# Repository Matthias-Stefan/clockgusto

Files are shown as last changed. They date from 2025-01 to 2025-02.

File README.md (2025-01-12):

# CLOCKGUSTO

This project is about adapting the original QLOCKTWO to a new format. The QLOCKTWO is a unique clock that displays time in words rather than numbers, with illuminated letters forming phrases such as "IT IS HALF PAST TEN."

## Features

- **Minute Precision:** Each illuminated dot represents one minute past the hour.
- **Word-Based Time Display:** The clock displays time using words for a more intuitive reading experience.
- **REST API:** Allows for remote adjustment of the time settings via a RESTful API.
- **Android App Integration:** An Android app is available to adjust the time and retrieve log information.

## Time Display Examples
In the default setting, the introductory words "ES IST" (IT IS) are shown at full and half hours. Here are some examples of how the time is displayed:

- 00:00: ES IST ZWÖLF UHR (It is twelve o'clock)
- 00:05: FÜNF NACH ZWÖLF (Five past twelve)
- 00:10: ZEHN NACH ZWÖLF (Ten past twelve)
- 00:15: VIERTEL EINS (Quarter past twelve)
- 00:20: ZWANZIG NACH ZWÖLF (Twenty past twelve)
- 00:25: FÜNF VOR HALB EINS (Five to half past twelve)
- 00:30: ES IST HALB EINS (It is half past twelve)
- 00:35: FÜNF NACH HALB EINS (Five past half past twelve)
- 00:40: ZWANZIG VOR EINS (Twenty to one)
- 00:45: DREIVIERTEL EINS (Three-quarters to one)
- 00:50: ZEHN VOR EINS (Ten to one)
- 00:55: FÜNF VOR EINS (Five to one)
- 01:00: ES IST EIN UHR (It is one o'clock)

## Character Map Layout
```
.                       .
  
  E S K I S T A F Ü N F 		   
  Z E H N Z W A N Z I G 
  D R E I V I E R T E L 
  V O R F U N K N A C H 
  H A L B A E L F Ü N F
  E I N S X A M Z W E I
  D R E I P M J V I E R
  S E C H S N L A C H T
  S I E B E N Z W Ö L F
  Z E H N E U N K U H R

.                       .
```
## ESP LED Indices Plan
```
113 112
  .   .

 0  1  2  3  4  5  6  7  8  9 10
 E  S  K  I  S  T  A  F  Ü  N  F 	

21 20 19 18 17 16 15 14 13 12 11	   
 Z  E  H  N  Z  W  A  N  Z  I  G 
  
22 23 24 25 26 27 28 29 30 31 32
 D  R  E  I  V  I  E  R  T  E  L

43 42 41 40 39 38 37 36 35 34 33 
 V  O  R  F  U  N  K  N  A  C  H 

44 45 46 47 48 49 50 51 52 53 54
 H  A  L  B  A  E  L  F  Ü  N  F

65 64 63 62 61 60 59 58 57 56 55
 E  I  N  S  X  A  M  Z  W  E  I

66 67 68 69 70 71 72 73 74 75 76
 D  R  E  I  P  M  J  V  I  E  R

87 86 85 84 83 82 81 80 79 78 77
 S  E  C  H  S  N  L  A  C  H  T

88 89 90 91 92 93 94 95 96 97 98
 S  I  E  B  E  N  Z  W  Ö  L  F

109 108 107 106 105 104 103 102 101 100 99
 Z   E   H   N   E   U   N   K   U   H   R

 110 111
  .   .
```

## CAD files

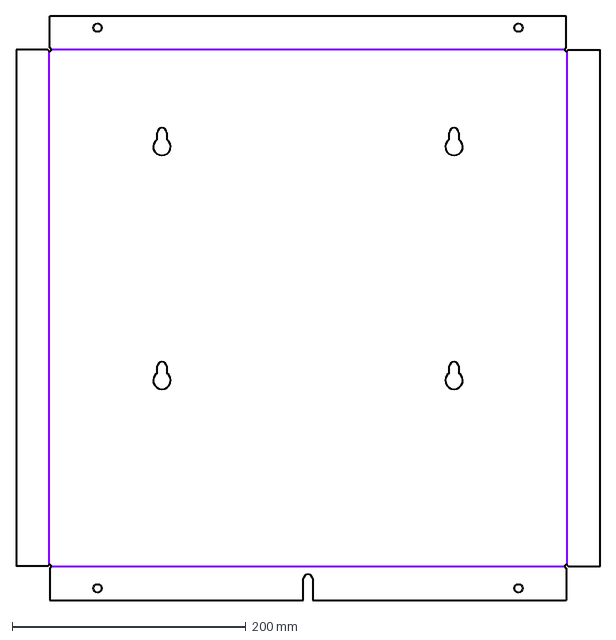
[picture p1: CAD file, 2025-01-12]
construction/02 Korpus.dxf
499.5 x 499.5 mm

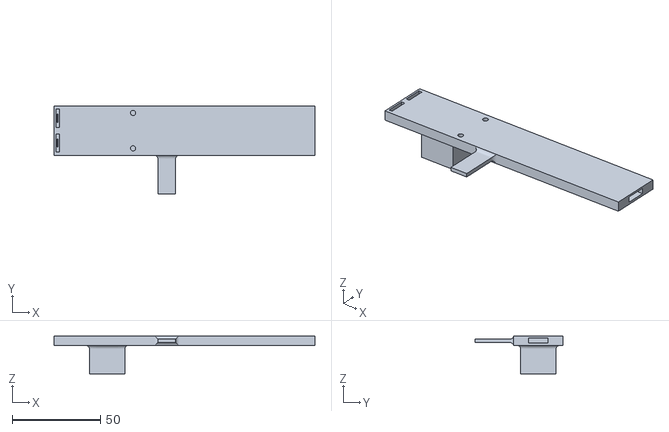
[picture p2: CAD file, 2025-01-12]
construction/printing/connector_a.stl
147.5 x 49.9 x 21.3

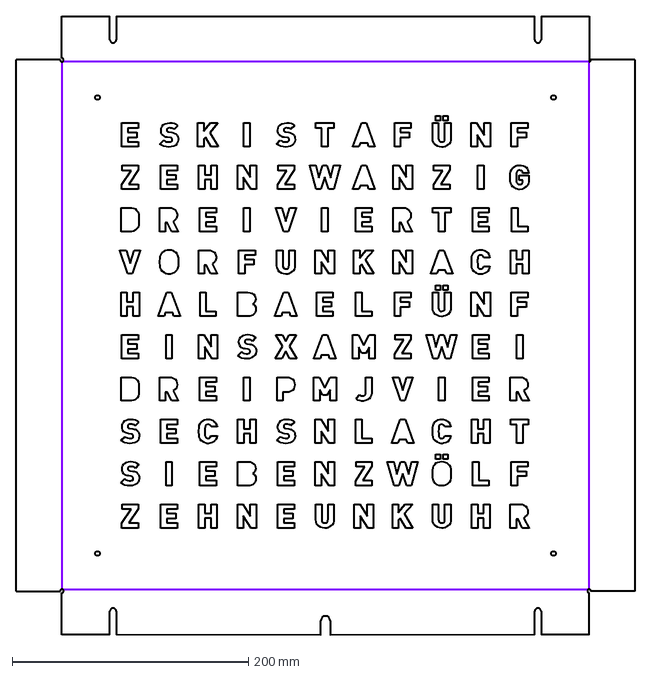
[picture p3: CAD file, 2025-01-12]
construction/01 Ziffernblatt.dxf
524.5 x 524.5 mm

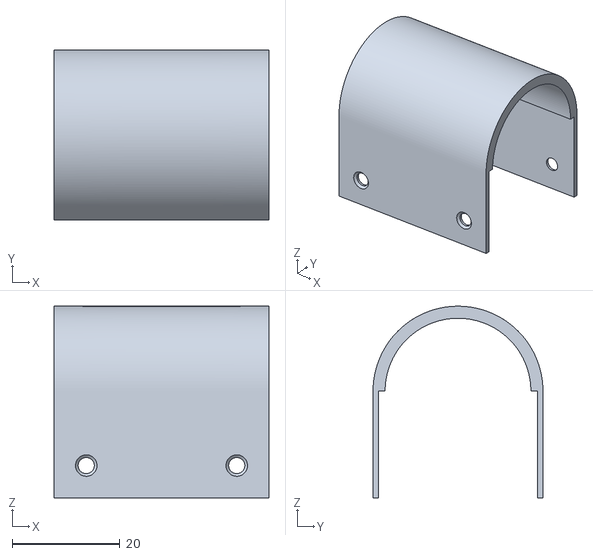
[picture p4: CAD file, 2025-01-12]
construction/printing/powerbank_case_top.stl
40.0 x 31.6 x 35.6

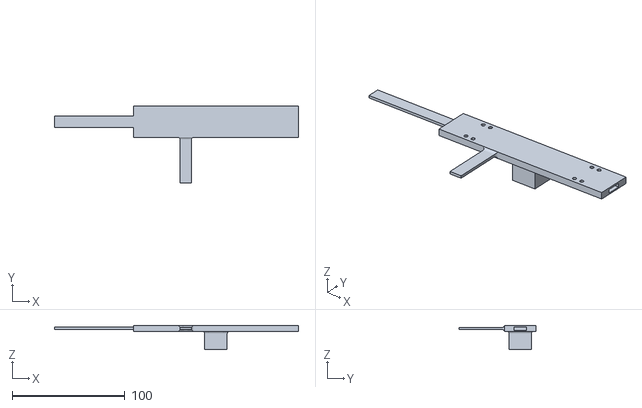
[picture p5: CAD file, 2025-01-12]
construction/connector_base_b.stl
216.5 x 68.4 x 21.3

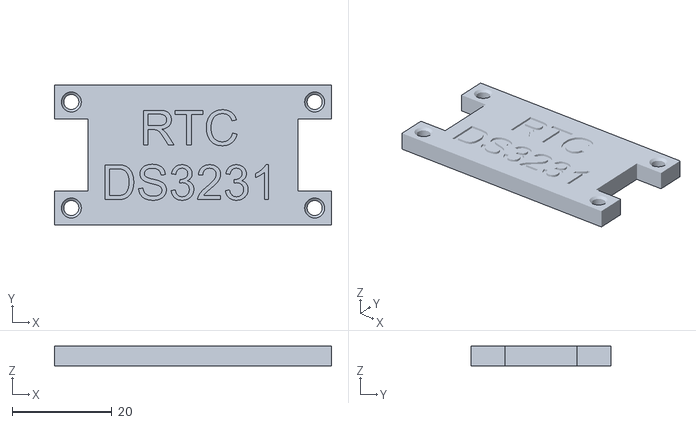
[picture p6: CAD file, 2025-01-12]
construction/printing/ds3231_case_top.stl
55.5 x 28.0 x 4.00

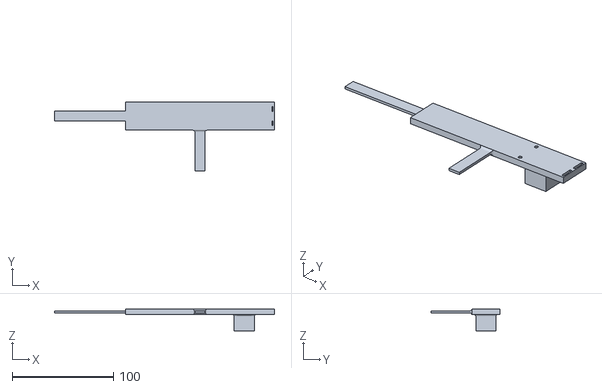
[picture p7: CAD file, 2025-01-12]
construction/connector_base_c.stl
217.5 x 68.4 x 21.3

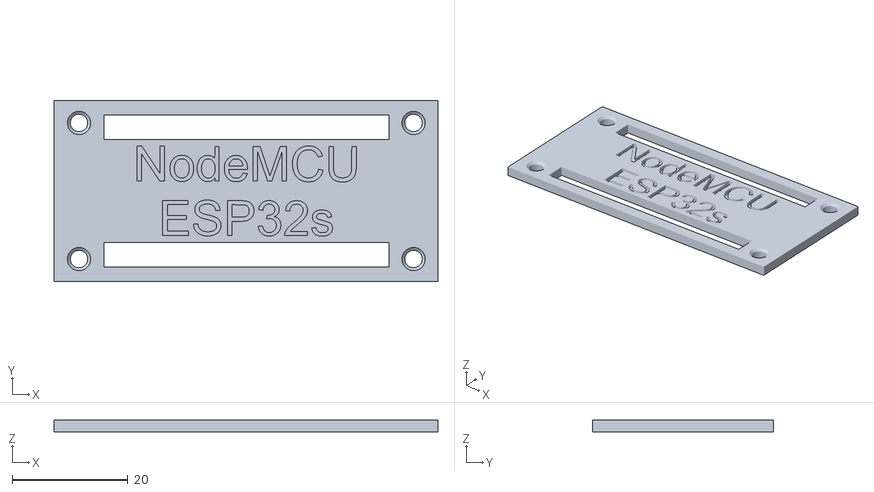
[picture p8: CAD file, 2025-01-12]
construction/printing/nodemcu esp32s_case_top.stl
66.2 x 31.2 x 2.00

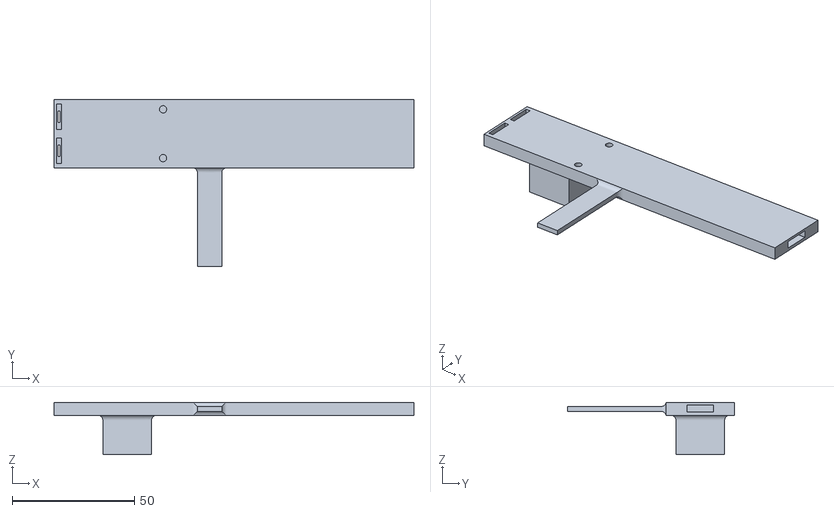
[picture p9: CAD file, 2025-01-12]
construction/connector_base_a.stl
147.5 x 68.4 x 21.3

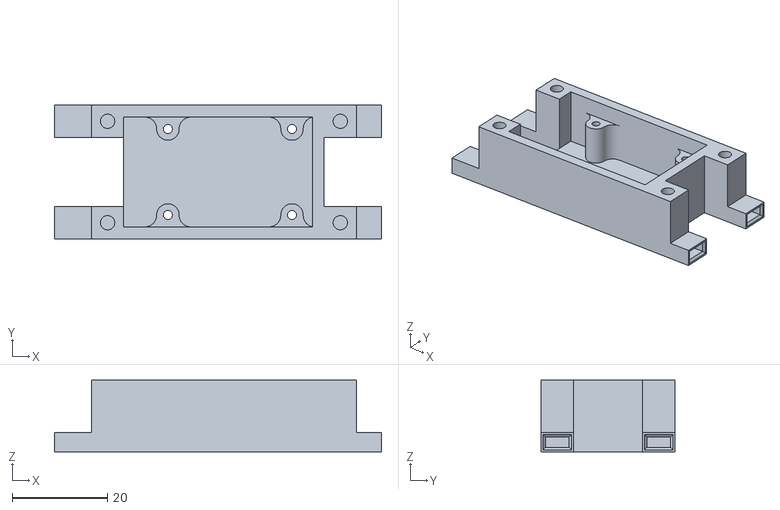
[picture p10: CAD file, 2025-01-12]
construction/printing/ds3231_case_bottom.stl
68.5 x 28.0 x 15.0

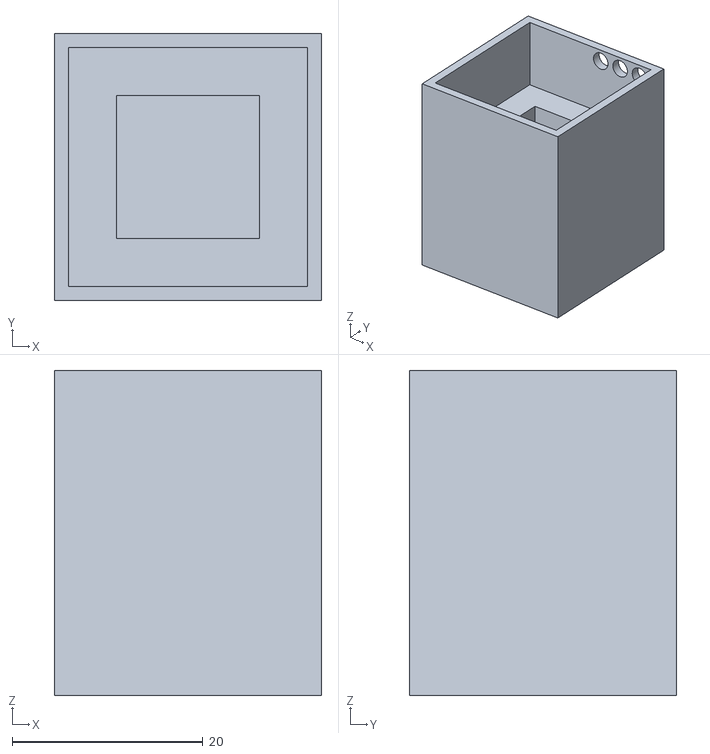
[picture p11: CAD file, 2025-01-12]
construction/printing/minute_tower.stl
28.0 x 28.0 x 34.0

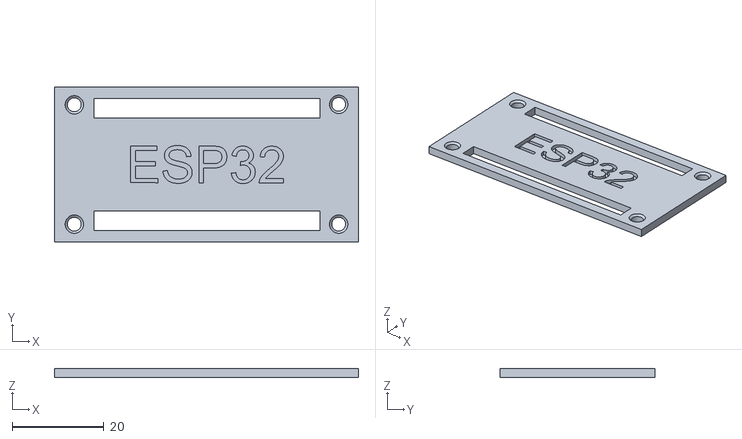
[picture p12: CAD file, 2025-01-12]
construction/printing/esp32 devkitc_v4_case_top.stl
66.2 x 33.8 x 2.00

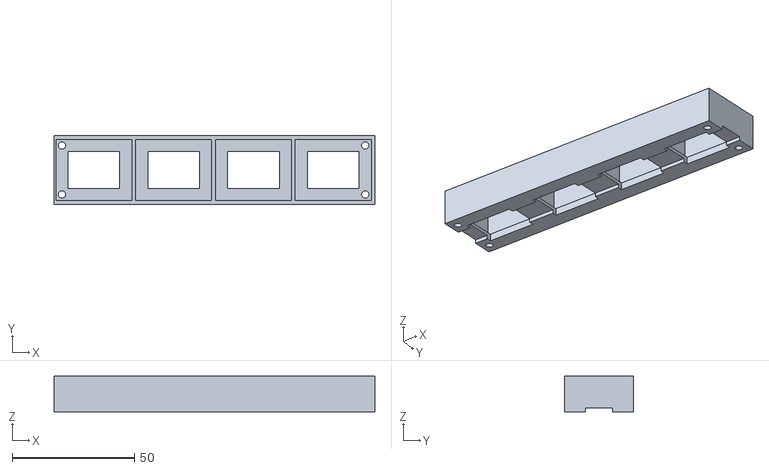
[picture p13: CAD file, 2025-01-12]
construction/printing/separator_4x_2.stl
131.2 x 28.0 x 14.7

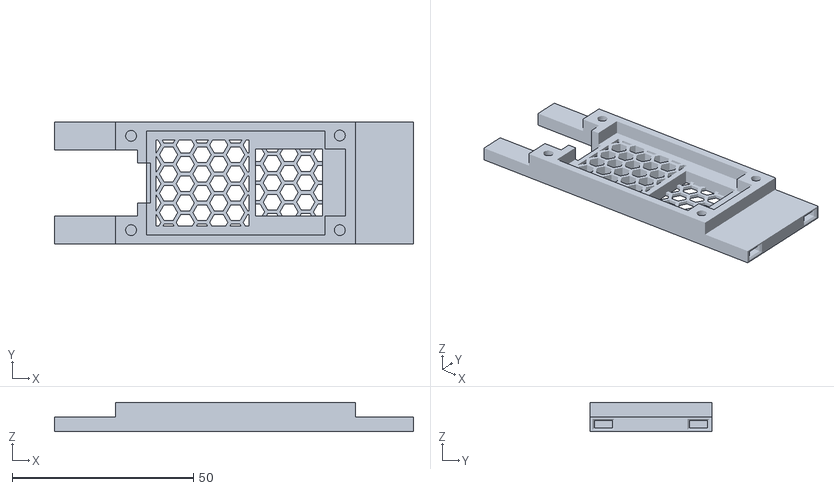
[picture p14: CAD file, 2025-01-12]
construction/printing/esp32 devkitc_v4_case_bottom.stl
99.0 x 33.8 x 8.00

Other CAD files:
construction/printing/connector_b.stl
construction/printing/antenna_nupsi.stl
construction/printing/separator_4x_1.stl
construction/printing/nodemcu esp32s_case_bottom.stl
construction/01 Ziffernblatt v4.f3d
construction/01 Ziffernblatt.dwg
construction/02 Korpus v42.f3d
construction/02 Korpus.dwg
construction/04 DS3231 v7.f3d
construction/05 Powerbank v7.f3d
construction/06 Antenna v4.f3d
construction/printing/connector_base_a.stl
construction/printing/connector_base_b.stl
construction/printing/connector_base_c.stl
construction/printing/connector_c.stl
construction/printing/connector_separator.3mf
construction/printing/powerbank_case_bottom.stl
construction/printing/separator_3x_1.stl

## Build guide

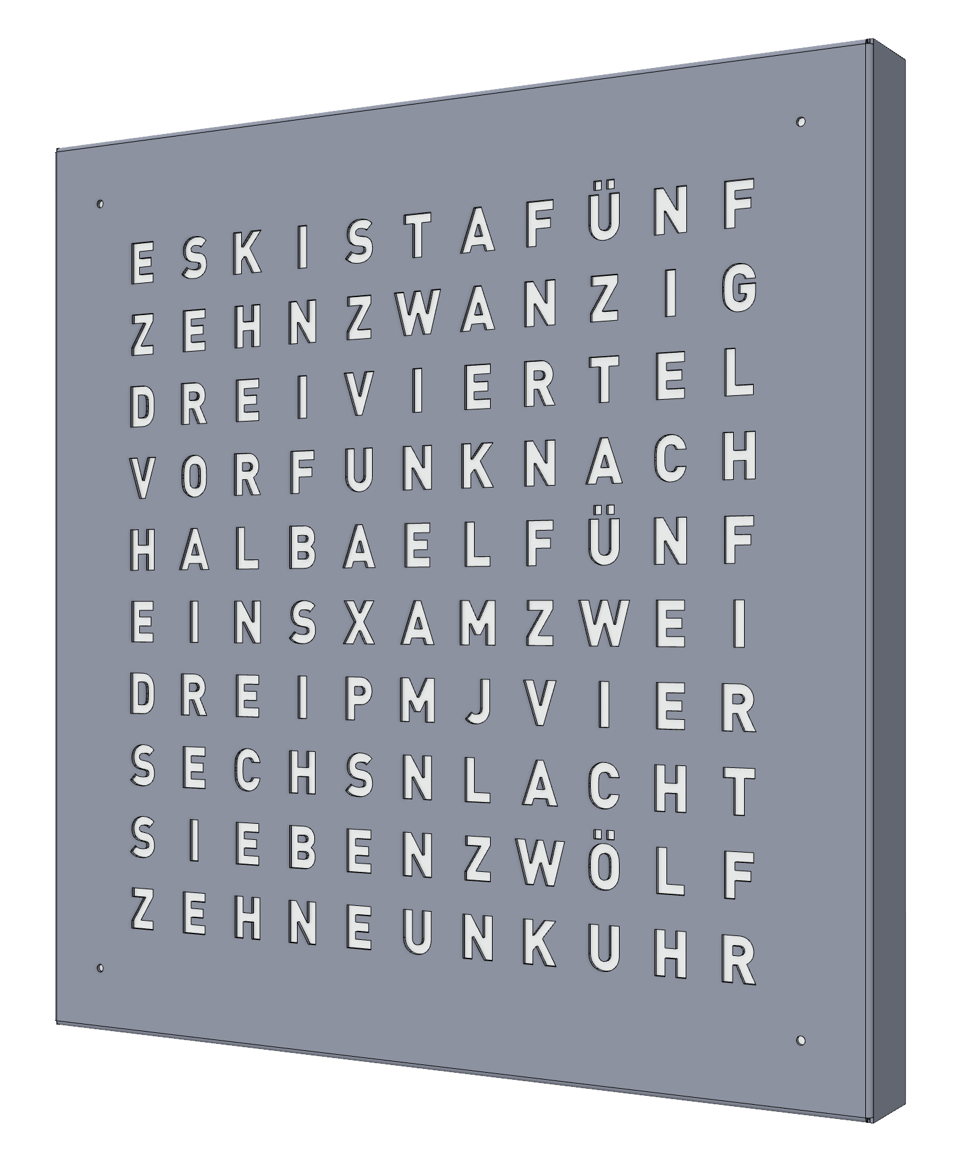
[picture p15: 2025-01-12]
construction/00 Uhr Michelle.png

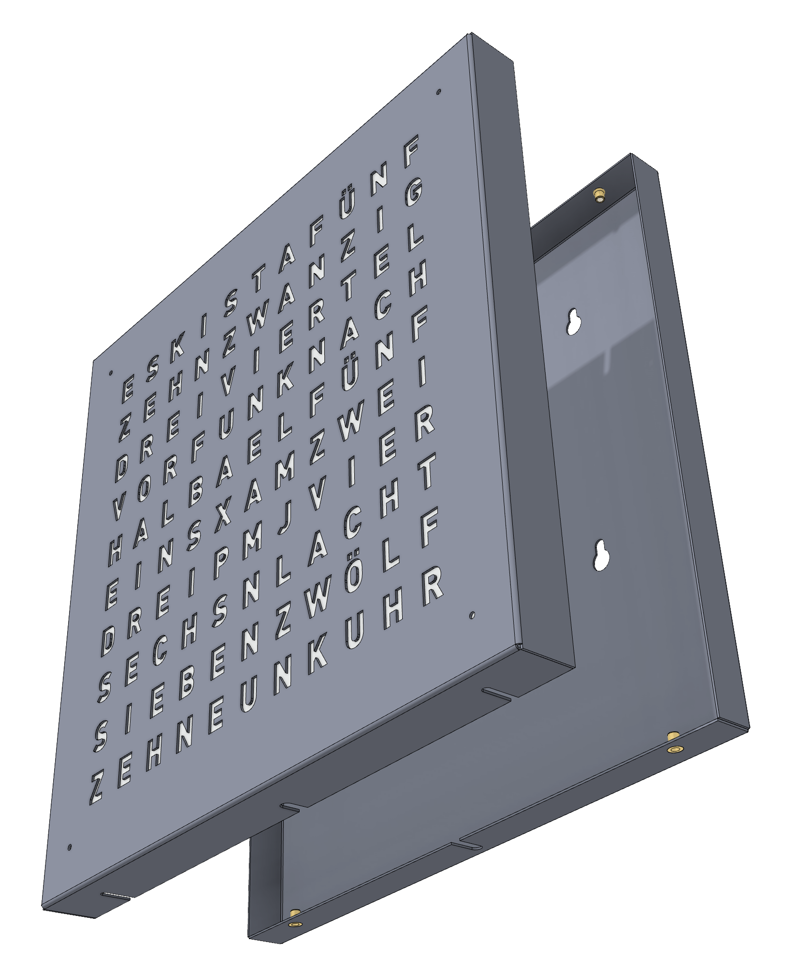
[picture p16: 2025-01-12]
construction/01 Uhr Michelle.png

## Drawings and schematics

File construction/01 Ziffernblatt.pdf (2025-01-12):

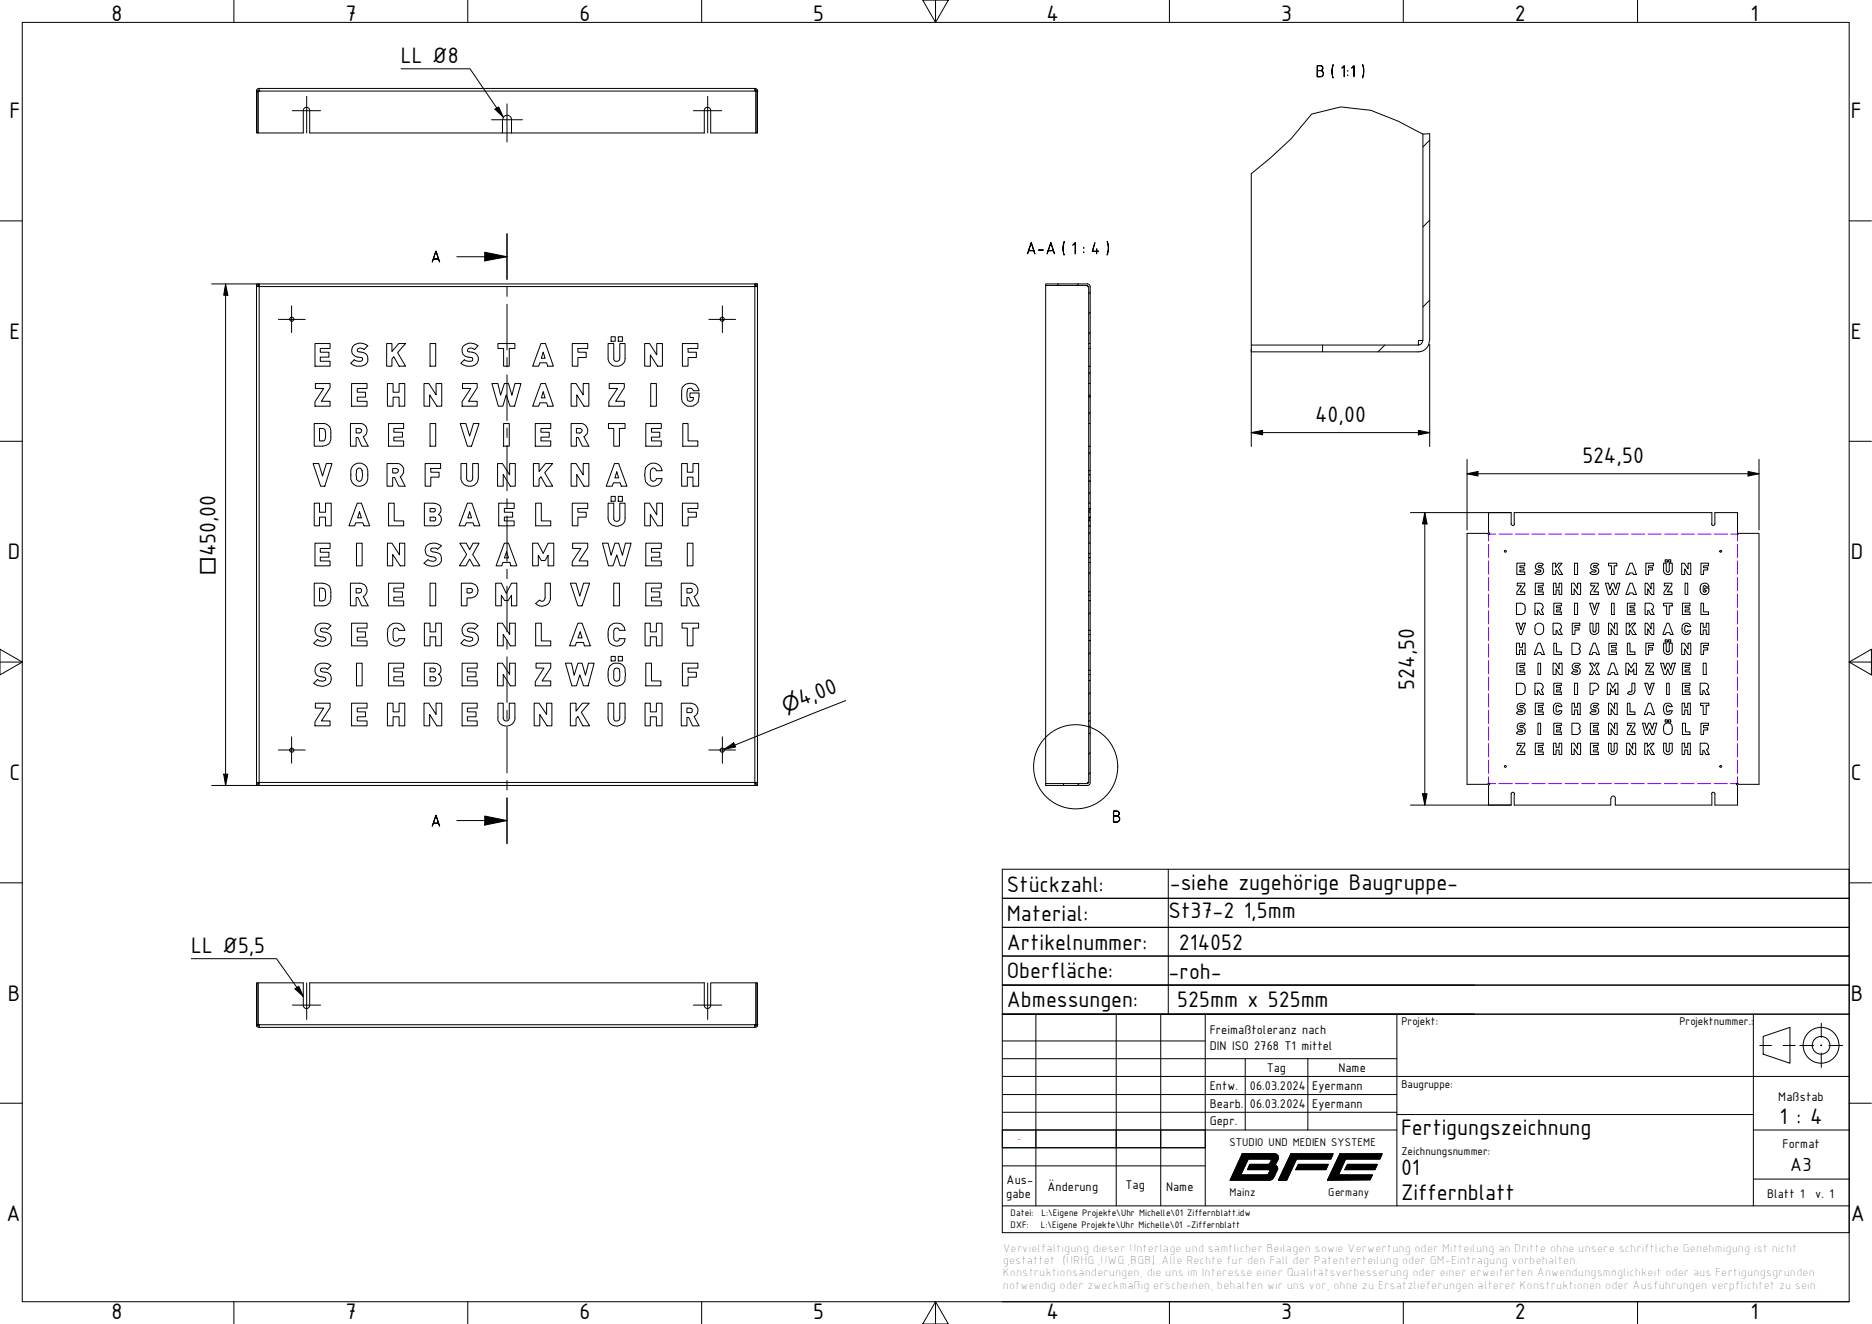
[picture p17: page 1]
Blatt 1 v. 1; DXF:; L:\Eigene Projekte\Uhr Michelle\01 -Ziffernblatt

Stückzahl: | -siehe zugehörige Baugruppe-
Material: | St37-2 1,5mm
Artikelnummer: | 214052
Oberfläche: | -roh-
Abmessungen: | 525mm x 525mm

Freimaßtoleranz nach DIN ISO 2768 T1 mittel | Projekt: Projektnummer.:

Tag | Name

Entw. | 06.03.2024 | Eyermann | Baugruppe: | Maßstab 1 : 4
Bearb. | 06.03.2024 | Eyermann
Gepr. | | | Fertigungszeichnung Fertigungszeichnung Zeichnungsnummer: 01 01 Ziffernblatt Ziffernblatt

STUDIO UND MEDIEN SYSTEME

Datei: L:\Eigene Projekte\Uhr Michelle\01 Ziffernblatt.idw
Vervielfältigung dieser Unterlage und sämtlicher Beilagen sowie Verwertung oder Mitteilung an Dritte ohne unsere schriftliche Genehmigung ist nicht
gestattet (URHG.,UWG.,BGB). Alle Rechte für den Fall der Patenterteilung oder GM-Eintragung vorbehalten.
Konstruktionsänderungen, die uns im Interesse einer Qualitätsverbesserung oder einer erweiterten Anwendungsmöglichkeit oder aus Fertigungsgründen
notwendig oder zweckmäßig erscheinen, behalten wir uns vor, ohne zu Ersatzlieferungen älterer Konstruktionen oder Ausführungen verpflichtet zu sein.

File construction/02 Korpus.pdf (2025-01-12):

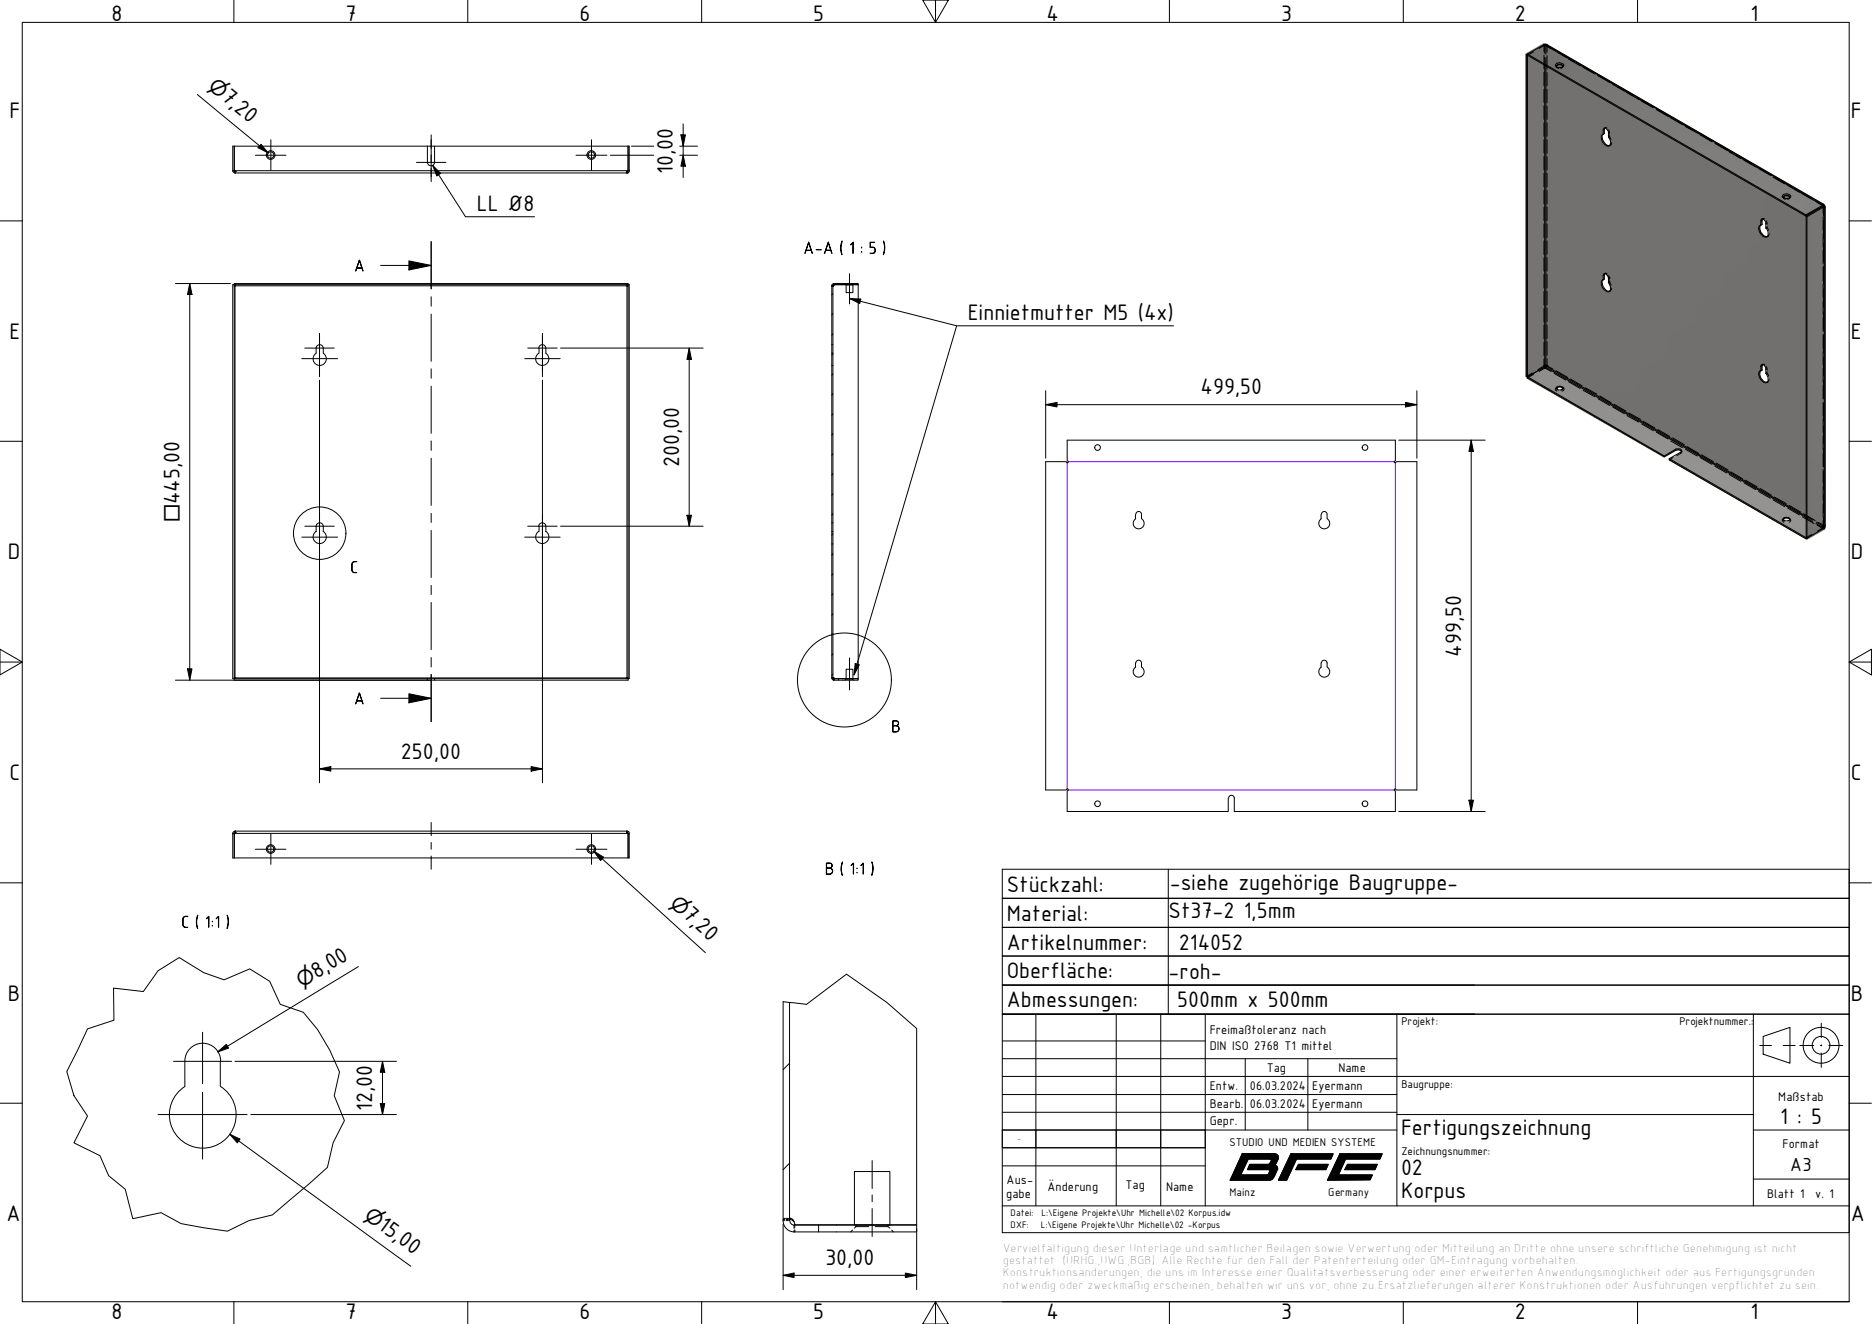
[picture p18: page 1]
Blatt 1 v. 1; DXF:; L:\Eigene Projekte\Uhr Michelle\02 -Korpus; Einnietmutter M5 (4x)

Stückzahl: | -siehe zugehörige Baugruppe-
Material: | St37-2 1,5mm
Artikelnummer: | 214052
Oberfläche: | -roh-
Abmessungen: | 500mm x 500mm

Freimaßtoleranz nach DIN ISO 2768 T1 mittel | Projekt: Projektnummer.:

Tag | Name

Entw. | 06.03.2024 | Eyermann | Baugruppe: | Maßstab 1 : 5
Bearb. | 06.03.2024 | Eyermann
Gepr. | | | Fertigungszeichnung Fertigungszeichnung Zeichnungsnummer: 02 02 Korpus Korpus

STUDIO UND MEDIEN SYSTEME

Datei: L:\Eigene Projekte\Uhr Michelle\02 Korpus.idw
Vervielfältigung dieser Unterlage und sämtlicher Beilagen sowie Verwertung oder Mitteilung an Dritte ohne unsere schriftliche Genehmigung ist nicht
gestattet (URHG.,UWG.,BGB). Alle Rechte für den Fall der Patenterteilung oder GM-Eintragung vorbehalten.
Konstruktionsänderungen, die uns im Interesse einer Qualitätsverbesserung oder einer erweiterten Anwendungsmöglichkeit oder aus Fertigungsgründen
notwendig oder zweckmäßig erscheinen, behalten wir uns vor, ohne zu Ersatzlieferungen älterer Konstruktionen oder Ausführungen verpflichtet zu sein.

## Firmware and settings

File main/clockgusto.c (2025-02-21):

/* ========================================================================
   $Project: Clock Gusto $
   $Date: 12.01.2025 $
   $Revision: $
   $Creator: Matthias Stefan $
   $Version: 2.0.0 $
   ======================================================================== */

/** sudo chmod a+rw /dev/ttyUSB0
 *  idf.py -p /dev/ttyUSB0 flash -b 115200 
 *  idf.py -p /dev/ttyUSBO monitor */

#include <stdbool.h>
#include <stdint.h>
#include <stdlib.h>
#include <string.h>

#include "freertos/FreeRTOS.h"
#include "freertos/task.h"
#include "esp_log.h"
#include "driver/rmt_tx.h"

#include "clockgusto.h"
#include "clockgusto_wifi.h"
#include "led_strip_encoder.h"
#include "rtc_ds3231.h"

#define BOARD "esp32"
#define TAG "clock gusto"
#define RMT_LED_STRIP_RESOLUTION_HZ 10000000 
#define RMT_LED_STRIP_GPIO_NUM      4
#define CLOCKGUSTO_CHASE_SPEED_MS   10

typedef struct _clockgusto_state_t
{
    clock_board_t clock_board;
    uint8_t led_strip_pixels[CLOCKGUSTO_NUM_LEDS * CLOCKGUSTO_BYTES_PER_LED];

    rmt_transmit_config_t tx_config;
    rmt_channel_handle_t led_chan;
    rmt_encoder_handle_t led_encoder;
} clockgusto_state_t;

clockgusto_state_t* state = NULL;

static void led_strip_hsv2rgb(uint32_t h, uint32_t s, uint32_t v, uint32_t* r, uint32_t* g, uint32_t* b);
static void clockgusto_set_board_time_mask();

void app_main(void)
{
    state = (clockgusto_state_t *)malloc(sizeof(clockgusto_state_t));
    if (!state)
    {
        ESP_LOGE(__FUNCTION__, "poor allocation. global structure cannot be created.");
    }

    ESP_LOGI(TAG, "Create RMT TX channel");
    state->led_chan = NULL;
    rmt_tx_channel_config_t tx_chan_config = {
        .clk_src = RMT_CLK_SRC_DEFAULT, // select source clock
        .gpio_num = RMT_LED_STRIP_GPIO_NUM,
        .mem_block_symbols = 64, // increase the block size can make the LED less flickering
        .resolution_hz = RMT_LED_STRIP_RESOLUTION_HZ,
        .trans_queue_depth = 4, // set the number of transactions that can be pending in the background
    };
    ESP_ERROR_CHECK(rmt_new_tx_channel(&tx_chan_config, &state->led_chan));

    ESP_LOGI(TAG, "Install led strip encoder");
    state->led_encoder = NULL;
    led_strip_encoder_config_t encoder_config = {
        .resolution = RMT_LED_STRIP_RESOLUTION_HZ,
    };
    ESP_ERROR_CHECK(rmt_new_led_strip_encoder(&encoder_config, &state->led_encoder));

    ESP_LOGI(TAG, "Enable RMT TX channel");
    ESP_ERROR_CHECK(rmt_enable(state->led_chan));

    ESP_LOGI(TAG, "Start LED rainbow chase");
    state->tx_config = (rmt_transmit_config_t){
        .loop_count = 0,
    };

    ESP_LOGI(TAG, "Enable RTC DS3231");
    uint8_t sda_pin = 21;
    uint8_t scl_pin = 22;
    ESP_ERROR_CHECK(rtc_ds3231_init(sda_pin, scl_pin, 100000));
    
    ESP_LOGI(TAG, "Startup clockgusto");
    clockgusto_startup();
   
#if true
    const char* compile_time = __TIME__;
    uint8_t hours = (uint8_t)strtol(compile_time, NULL, 10);
    uint8_t minutes = (uint8_t)strtol(compile_time + 3, NULL, 10);
    uint8_t seconds = (uint8_t)strtol(compile_time + 6, NULL, 10);
    ESP_ERROR_CHECK(rtc_ds3231_set_time(hours, minutes, seconds));
#else
    int8_t hours = 11;
    int8_t minutes = 10;
    int8_t seconds = 00;
    ESP_ERROR_CHECK(rtc_ds3231_set_time(hours, minutes, seconds));
#endif

    state->clock_board.hours = hours;
    state->clock_board.minutes = minutes;
    state->clock_board.seconds = seconds;
    ESP_LOGI(TAG, "Start clock");
    while (true) 
    {
        ESP_LOGI(TAG, "Update clock");
        clockgusto_update();

        ESP_LOGI(TAG, "Show clock");
        clockgusto_show();

        //ESP_LOGI(TAG, "Reset clock");
        //clockgusto_reset();
        
        vTaskDelay(pdMS_TO_TICKS(100));
    }
}

void clockgusto_startup()
{
    clock_board_t* clock_board = &state->clock_board;

    clock_board->clock_word_boundary_table[CLOCK_WORD_ES] = (clock_word_boundary_t){  
        .index = 0,
        .size = 2
    };
    clock_board->clock_word_boundary_table[CLOCK_WORD_IST] = (clock_word_boundary_t){ 
        .index = 3, 
        .size = 3 
    };      
    clock_board->clock_word_boundary_table[CLOCK_WORD_FUENF_1] = (clock_word_boundary_t){ 
        .index = 7, 
        .size = 4 
    };
    clock_board->clock_word_boundary_table[CLOCK_WORD_ZEHN_1] = (clock_word_boundary_t){ 
        .index = 18, 
        .size = 4 
    };
    clock_board->clock_word_boundary_table[CLOCK_WORD_ZWANZIG] = (clock_word_boundary_t){ 
        .index = 11, 
        .size = 7 
    };
    clock_board->clock_word_boundary_table[CLOCK_WORD_DREIVIERTEL] = (clock_word_boundary_t){ 
        .index = 22, 
        .size = 11 
    };
    clock_board->clock_word_boundary_table[CLOCK_WORD_VIERTEL] = (clock_word_boundary_t){ 
        .index = 26, 
        .size = 7 
    };
    clock_board->clock_word_boundary_table[CLOCK_WORD_VOR] = (clock_word_boundary_t){ 
        .index = 41, 
        .size = 3 
    };
    clock_board->clock_word_boundary_table[CLOCK_WORD_NACH] = (clock_word_boundary_t){ 
        .index = 33, 
        .size = 4 
    };
    clock_board->clock_word_boundary_table[CLOCK_WORD_HALB] = (clock_word_boundary_t){ 
        .index = 44, 
        .size = 4 
    };
    clock_board->clock_word_boundary_table[CLOCK_WORD_EIN] = (clock_word_boundary_t){ 
        .index = 63, 
        .size = 3 
    };
    clock_board->clock_word_boundary_table[CLOCK_WORD_EINS] = (clock_word_boundary_t){ 
        .index = 62, 
        .size = 4 
    };
    clock_board->clock_word_boundary_table[CLOCK_WORD_ZWEI] = (clock_word_boundary_t){ 
        .index = 55, 
        .size = 4 
    };
    clock_board->clock_word_boundary_table[CLOCK_WORD_DREI] = (clock_word_boundary_t){ 
        .index = 66, 
        .size = 4 
    };
    clock_board->clock_word_boundary_table[CLOCK_WORD_VIER] = (clock_word_boundary_t){ 
        .index = 73, 
        .size = 4 
    };
    clock_board->clock_word_boundary_table[CLOCK_WORD_FUENF_2] = (clock_word_boundary_t){ 
        .index = 51, 
        .size = 4
    };
    clock_board->clock_word_boundary_table[CLOCK_WORD_SECHS] = (clock_word_boundary_t){ 
        .index = 83, 
        .size = 5 
    };
    clock_board->clock_word_boundary_table[CLOCK_WORD_SIEBEN] = (clock_word_boundary_t){ 
        .index = 88, 
        .size = 6 
    };
    clock_board->clock_word_boundary_table[CLOCK_WORD_ACHT] = (clock_word_boundary_t){ 
        .index = 77, 
        .size = 4 
    };
    clock_board->clock_word_boundary_table[CLOCK_WORD_NEUN] = (clock_word_boundary_t){ 
        .index = 103, 
        .size = 4 
    };
    clock_board->clock_word_boundary_table[CLOCK_WORD_ZEHN_2] = (clock_word_boundary_t){ 
        .index = 106, 
        .size = 4 
    };
    clock_board->clock_word_boundary_table[CLOCK_WORD_ELF] = (clock_word_boundary_t){ 
        .index = 49, 
        .size = 3 
    };
    clock_board->clock_word_boundary_table[CLOCK_WORD_ZWOELF] = (clock_word_boundary_t){ 
        .index = 94, 
        .size = 5 
    };
    clock_board->clock_word_boundary_table[CLOCK_WORD_UHR] = (clock_word_boundary_t){ 
        .index = 99, 
        .size = 3 
    };
    clock_board->clock_word_boundary_table[CLOCK_MINUTE_1] = (clock_word_boundary_t){ 
        .index = 113, 
        .size = 1 
    };
    clock_board->clock_word_boundary_table[CLOCK_MINUTE_2] = (clock_word_boundary_t){ 
        .index = 112, 
        .size = 1 
    };
    clock_board->clock_word_boundary_table[CLOCK_MINUTE_3] = (clock_word_boundary_t){ 
        .index = 111, 
        .size = 1 
    };
    clock_board->clock_word_boundary_table[CLOCK_MINUTE_4] = (clock_word_boundary_t){ 
        .index = 110, 
        .size = 1 
    };
}

void clockgusto_update()
{
    ESP_LOGI(__FUNCTION__, "invoked");
    clock_board_t* clock_board = &state->clock_board;
    uint8_t hours, minutes, seconds; 
    rtc_ds3231_get_time(&hours, &minutes, &seconds); 
   
    if (clock_board->hours != hours || clock_board->minutes != minutes)
    {
        clock_board->flip = true;
        clock_board->hours = hours;
        clock_board->minutes = minutes;
        clock_board->seconds = seconds;
    }

    clockgusto_set_board_time_mask();

    for (uint16_t led_idx = 0; led_idx < CLOCKGUSTO_NUM_LEDS; ++led_idx)
    {
        clock_board->leds[led_idx].on = false;
    }

    for (uint8_t mask_idx = 0; mask_idx < CLOCK_WORD_COUNT; ++mask_idx)
    {
        uint32_t mask = 0x0 | 1 << mask_idx;
        uint32_t mask_result = mask & clock_board->time_mask;
        clock_word_boundary_t boundary = clock_board->clock_word_boundary_table[(clock_word_t)mask_idx];

        if (mask_result > 0)
        {
            for (uint16_t led_idx = boundary.index; 
                 led_idx < (boundary.index + boundary.size);
                 ++led_idx)
            {
                clock_board->leds[led_idx].on = true;
            }
        }
    }
}

void clockgusto_show()
{
    static uint32_t red = 0;
    static uint32_t green = 0;
    static uint32_t blue = 0;
    static uint16_t hue = 0;
    static uint16_t start_rgb = 0;

    ESP_LOGI(__FUNCTION__, "prob1");
    if (state->clock_board.flip == true)
    {
        for (uint8_t mask_idx = 0; mask_idx < CLOCK_WORD_COUNT; ++mask_idx)
        {
            uint32_t mask = 0x0 | 1 << mask_idx;
            uint32_t mask_result = mask & state->clock_board.time_mask;

            if (mask_result > 0)
            {    
                const clock_word_str_t word = clock_word_str[(uint32_t)mask_idx];
                ESP_LOGI(__FUNCTION__, "%s", word.data);
            }
        }
    }
   
    ESP_LOGI(__FUNCTION__, "prob2");
    if (state->clock_board.flip == true)
    {
        for (int led_idx = 0; 
             led_idx < CLOCKGUSTO_NUM_LEDS * CLOCKGUSTO_BYTES_PER_LED; 
             led_idx += CLOCKGUSTO_BYTES_PER_LED)
        {
            led_strip_hsv2rgb(0, 0, 0, &red, &green, &blue);
            state->led_strip_pixels[led_idx + 0] = green;
            state->led_strip_pixels[led_idx + 1] = blue;
            state->led_strip_pixels[led_idx + 2] = red;
        }
    }

    ESP_LOGI(__FUNCTION__, "prob3");
    for (int led_idx = 0; led_idx < CLOCKGUSTO_NUM_LEDS; led_idx += 1) 
    {
        if (state->clock_board.leds[led_idx].on == true)
        {
            hue = led_idx * 360 / CLOCKGUSTO_NUM_LEDS + start_rgb;
            led_strip_hsv2rgb(hue, 100, 100, &red, &green, &blue);
            int color_offset = led_idx * CLOCKGUSTO_BYTES_PER_LED; 
            state->led_strip_pixels[color_offset + 0] = green;
            state->led_strip_pixels[color_offset + 1] = blue;
            state->led_strip_pixels[color_offset + 2] = red;
        }
    }

    ESP_LOGI(__FUNCTION__, "prob4");
    ESP_ERROR_CHECK(rmt_transmit(state->led_chan, 
                                 state->led_encoder, 
                                 state->led_strip_pixels, 
                                 sizeof(state->led_strip_pixels), 
                                 &state->tx_config));

    ESP_ERROR_CHECK(rmt_tx_wait_all_done(state->led_chan, portMAX_DELAY));
    vTaskDelay(pdMS_TO_TICKS(20));
    start_rgb = (start_rgb + 1) % 256;
}

void clockgusto_reset()
{
    for (uint16_t led_idx = 0; led_idx < CLOCKGUSTO_NUM_LEDS; ++led_idx)
    {
        state->clock_board.leds[led_idx].on = false;
    }
    
    state->clock_board.flip = false;
}

static void led_strip_hsv2rgb(uint32_t h, uint32_t s, uint32_t v, uint32_t* r, uint32_t* g, uint32_t* b)
{
    h %= 360;
    uint32_t rgb_max = v * 2.55f;
    uint32_t rgb_min = rgb_max * (100 - s) / 100.0f;

    uint32_t i = h / 60;
    uint32_t diff = h % 60;

    uint32_t rgb_adj = (rgb_max - rgb_min) * diff / 60;

    switch (i) 
    {
    case 0:
        *r = rgb_max;
        *g = rgb_min + rgb_adj;
        *b = rgb_min;
        break;
    case 1:
        *r = rgb_max - rgb_adj;
        *g = rgb_max;
        *b = rgb_min;
        break;
    case 2:
        *r = rgb_min;
        *g = rgb_max;
        *b = rgb_min + rgb_adj;
        break;
    case 3:
        *r = rgb_min;
        *g = rgb_max - rgb_adj;
        *b = rgb_max;
        break;
    case 4:
        *r = rgb_min + rgb_adj;
        *g = rgb_min;
        *b = rgb_max;
        break;
    default:
        *r = rgb_max;
        *g = rgb_min;
        *b = rgb_max - rgb_adj;
        break;
    }
}

static void clockgusto_set_board_time_mask()
{
    uint8_t hours = state->clock_board.hours;
    uint8_t minutes = state->clock_board.minutes;
    uint8_t seconds = state->clock_board.seconds;
    (void)seconds;

    if (!(minutes < 15 || (20 <= minutes&& minutes < 25))) 
    {
        hours = (hours + 1) % 24; 
    }

    state->clock_board.time_mask = 0x0;
    switch (hours)
    {
        case 0:
        case 12: 
        {
            state->clock_board.time_mask |= 1 << CLOCK_WORD_ZWOELF;
        } break;
        case 1:
        case 13:
        {
            if (minutes < 5)
            {
                state->clock_board.time_mask |= 1 << CLOCK_WORD_EIN;
            }
            else
            {
                state->clock_board.time_mask |= 1 << CLOCK_WORD_EINS;
            }
        } break;
        case 2:
        case 14:
        {
            state->clock_board.time_mask |= 1 << CLOCK_WORD_ZWEI;
        } break;
        case 3:
        case 15:
        {
            state->clock_board.time_mask |= 1 << CLOCK_WORD_DREI;
        } break;
        case 4:
        case 16:
        {
            state->clock_board.time_mask |= 1 << CLOCK_WORD_VIER;
        } break;
        case 5:
        case 17:
        {
            state->clock_board.time_mask |= 1 << CLOCK_WORD_FUENF_2;
        } break;
        case 6:
        case 18:
        {
            state->clock_board.time_mask |= 1 << CLOCK_WORD_SECHS;
        } break;
        case 7:
        case 19:
        {
            state->clock_board.time_mask |= 1 << CLOCK_WORD_SIEBEN;
        } break;
        case 8:
        case 20:
        {
            state->clock_board.time_mask |= 1 << CLOCK_WORD_ACHT;
        } break;
        case 9:
        case 21:
        {
            state->clock_board.time_mask |= 1 << CLOCK_WORD_NEUN;
        } break;
        case 10:
        case 22:
        {
            state->clock_board.time_mask |= 1 << CLOCK_WORD_ZEHN_2;
        } break;
        case 11:
        case 23:
        {
            state->clock_board.time_mask |= 1 << CLOCK_WORD_ELF;
        } break;
    }

    if (0 <= minutes && minutes < 5) 
    {
        state->clock_board.time_mask |= 1 << CLOCK_WORD_ES;
        state->clock_board.time_mask |= 1 << CLOCK_WORD_IST;
        state->clock_board.time_mask |= 1 << CLOCK_WORD_UHR;
    }
    else if (5 <= minutes && minutes < 10)
    {
        state->clock_board.time_mask |= 1 << CLOCK_WORD_FUENF_1;
        state->clock_board.time_mask |= 1 << CLOCK_WORD_NACH;
    }
    else if (10 <= minutes && minutes < 15)
    {
        state->clock_board.time_mask |= 1 << CLOCK_WORD_ZEHN_1;
        state->clock_board.time_mask |= 1 << CLOCK_WORD_NACH;
    }
    else if (15 <= minutes && minutes < 20)
    {
        state->clock_board.time_mask |= 1 << CLOCK_WORD_VIERTEL;
    }
    else if (20 <= minutes && minutes < 25)
    {
        state->clock_board.time_mask |= 1 << CLOCK_WORD_ZWANZIG;
        state->clock_board.time_mask |= 1 << CLOCK_WORD_NACH;
    }
    else if (25 <= minutes && minutes < 30)
    {
        state->clock_board.time_mask |= 1 << CLOCK_WORD_FUENF_1;
        state->clock_board.time_mask |= 1 << CLOCK_WORD_VOR;
        state->clock_board.time_mask |= 1 << CLOCK_WORD_HALB;
    }
    else if (30 <= minutes && minutes < 35)
    {
        state->clock_board.time_mask |= 1 << CLOCK_WORD_ES;
        state->clock_board.time_mask |= 1 << CLOCK_WORD_IST;
        state->clock_board.time_mask |= 1 << CLOCK_WORD_HALB;
    }
    else if (35 <= minutes && minutes < 40)
    {
        state->clock_board.time_mask |= 1 << CLOCK_WORD_FUENF_1;
        state->clock_board.time_mask |= 1 << CLOCK_WORD_NACH;
        state->clock_board.time_mask |= 1 << CLOCK_WORD_HALB;
    }
    else if (40 <= minutes && minutes < 45)
    {
        state->clock_board.time_mask |= 1 << CLOCK_WORD_ZWANZIG;
        state->clock_board.time_mask |= 1 << CLOCK_WORD_VOR;
    }
    else if (45 <= minutes && minutes < 50)
    {
        state->clock_board.time_mask |= 1 << CLOCK_WORD_DREIVIERTEL;
    }
    else if (50 <= minutes && minutes < 55)
    {
        state->clock_board.time_mask |= 1 << CLOCK_WORD_ZEHN_1;
        state->clock_board.time_mask |= 1 << CLOCK_WORD_VOR;
    }
    else // 55 <= minutes && minutes 59
    {
        state->clock_board.time_mask |= 1 << CLOCK_WORD_FUENF_1;
        state->clock_board.time_mask |= 1 << CLOCK_WORD_VOR;
    }    

    if (minutes % 5 == 1)
    {
        state->clock_board.time_mask |= 1 << CLOCK_MINUTE_1;
    }
    else if (minutes % 5 == 2)
    {
        state->clock_board.time_mask |= 1 << CLOCK_MINUTE_1;
        state->clock_board.time_mask |= 1 << CLOCK_MINUTE_2;
    }
    else if (minutes % 5 == 3)
    {
        state->clock_board.time_mask |= 1 << CLOCK_MINUTE_1;
        state->clock_board.time_mask |= 1 << CLOCK_MINUTE_2;
        state->clock_board.time_mask |= 1 << CLOCK_MINUTE_3;
    }
    else if (minutes % 5 == 4)
    {
        state->clock_board.time_mask |= 1 << CLOCK_MINUTE_1;
        state->clock_board.time_mask |= 1 << CLOCK_MINUTE_2;
        state->clock_board.time_mask |= 1 << CLOCK_MINUTE_3;
        state->clock_board.time_mask |= 1 << CLOCK_MINUTE_4;
    }
    else
    {
        state->clock_board.time_mask |= 0 << CLOCK_MINUTE_1;
        state->clock_board.time_mask |= 0 << CLOCK_MINUTE_2;
        state->clock_board.time_mask |= 0 << CLOCK_MINUTE_3;
        state->clock_board.time_mask |= 0 << CLOCK_MINUTE_4;
    }
}

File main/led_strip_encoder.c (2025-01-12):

/*
 * SPDX-FileCopyrightText: 2021-2022 Espressif Systems (Shanghai) CO LTD
 *
 * SPDX-License-Identifier: Apache-2.0
 */

#include "esp_check.h"
#include "led_strip_encoder.h"

static const char *TAG = "led_encoder";

typedef struct 
{
    rmt_encoder_t base;
    rmt_encoder_t *bytes_encoder;
    rmt_encoder_t *copy_encoder;
    int state;
    rmt_symbol_word_t reset_code;
} rmt_led_strip_encoder_t;

static size_t rmt_encode_led_strip(rmt_encoder_t *encoder, rmt_channel_handle_t channel, const void *primary_data, size_t data_size, rmt_encode_state_t *ret_state)
{
    rmt_led_strip_encoder_t *led_encoder = __containerof(encoder, rmt_led_strip_encoder_t, base);
    rmt_encoder_handle_t bytes_encoder = led_encoder->bytes_encoder;
    rmt_encoder_handle_t copy_encoder = led_encoder->copy_encoder;
    rmt_encode_state_t session_state = RMT_ENCODING_RESET;
    rmt_encode_state_t state = RMT_ENCODING_RESET;
    size_t encoded_symbols = 0;
    switch (led_encoder->state) 
    {
    case 0: // send RGB data
        encoded_symbols += bytes_encoder->encode(bytes_encoder, channel, primary_data, data_size, &session_state);
        if (session_state & RMT_ENCODING_COMPLETE) 
        {
            led_encoder->state = 1; // switch to next state when current encoding session finished
        }
        if (session_state & RMT_ENCODING_MEM_FULL) 
        {
            state |= RMT_ENCODING_MEM_FULL;
            goto out; // yield if there's no free space for encoding artifacts
        }
    // fall-through
    case 1: // send reset code
        encoded_symbols += copy_encoder->encode(copy_encoder, channel, &led_encoder->reset_code,
                                                sizeof(led_encoder->reset_code), &session_state);
        if (session_state & RMT_ENCODING_COMPLETE) 
        {
            led_encoder->state = RMT_ENCODING_RESET; // back to the initial encoding session
            state |= RMT_ENCODING_COMPLETE;
        }
        if (session_state & RMT_ENCODING_MEM_FULL) 
        {
            state |= RMT_ENCODING_MEM_FULL;
            goto out; // yield if there's no free space for encoding artifacts
        }
    }
out:
    *ret_state = state;
    return encoded_symbols;
}

static esp_err_t rmt_del_led_strip_encoder(rmt_encoder_t *encoder)
{
    rmt_led_strip_encoder_t *led_encoder = __containerof(encoder, rmt_led_strip_encoder_t, base);
    rmt_del_encoder(led_encoder->bytes_encoder);
    rmt_del_encoder(led_encoder->copy_encoder);
    free(led_encoder);
    return ESP_OK;
}

static esp_err_t rmt_led_strip_encoder_reset(rmt_encoder_t *encoder)
{
    rmt_led_strip_encoder_t *led_encoder = __containerof(encoder, rmt_led_strip_encoder_t, base);
    rmt_encoder_reset(led_encoder->bytes_encoder);
    rmt_encoder_reset(led_encoder->copy_encoder);
    led_encoder->state = RMT_ENCODING_RESET;
    return ESP_OK;
}

esp_err_t rmt_new_led_strip_encoder(const led_strip_encoder_config_t *config, rmt_encoder_handle_t *ret_encoder)
{
    esp_err_t ret = ESP_OK;
    rmt_led_strip_encoder_t *led_encoder = NULL;
    ESP_GOTO_ON_FALSE(config && ret_encoder, ESP_ERR_INVALID_ARG, err, TAG, "invalid argument");
    led_encoder = rmt_alloc_encoder_mem(sizeof(rmt_led_strip_encoder_t));
    ESP_GOTO_ON_FALSE(led_encoder, ESP_ERR_NO_MEM, err, TAG, "no mem for led strip encoder");
    led_encoder->base.encode = rmt_encode_led_strip;
    led_encoder->base.del = rmt_del_led_strip_encoder;
    led_encoder->base.reset = rmt_led_strip_encoder_reset;
    // different led strip might have its own timing requirements, following parameter is for WS2812
    rmt_bytes_encoder_config_t bytes_encoder_config = {
        .bit0 = {
            .level0 = 1,
            .duration0 = 0.3 * config->resolution / 1000000, // T0H=0.3us
            .level1 = 0,
            .duration1 = 0.9 * config->resolution / 1000000, // T0L=0.9us
        },
        .bit1 = {
            .level0 = 1,
            .duration0 = 0.9 * config->resolution / 1000000, // T1H=0.9us
            .level1 = 0,
            .duration1 = 0.3 * config->resolution / 1000000, // T1L=0.3us
        },
        .flags.msb_first = 1 // WS2812 transfer bit order: G7...G0R7...R0B7...B0
    };
    ESP_GOTO_ON_ERROR(rmt_new_bytes_encoder(&bytes_encoder_config, &led_encoder->bytes_encoder), err, TAG, "create bytes encoder failed");
    rmt_copy_encoder_config_t copy_encoder_config = {};
    ESP_GOTO_ON_ERROR(rmt_new_copy_encoder(&copy_encoder_config, &led_encoder->copy_encoder), err, TAG, "create copy encoder failed");

    uint32_t reset_ticks = config->resolution / 1000000 * 50 / 2; // reset code duration defaults to 50us
    led_encoder->reset_code = (rmt_symbol_word_t) {
        .level0 = 0,
        .duration0 = reset_ticks,
        .level1 = 0,
        .duration1 = reset_ticks,
    };
    *ret_encoder = &led_encoder->base;
    return ESP_OK;
err:
    if (led_encoder) {
        if (led_encoder->bytes_encoder) {
            rmt_del_encoder(led_encoder->bytes_encoder);
        }
        if (led_encoder->copy_encoder) {
            rmt_del_encoder(led_encoder->copy_encoder);
        }
        free(led_encoder);
    }
    return ret;
}
